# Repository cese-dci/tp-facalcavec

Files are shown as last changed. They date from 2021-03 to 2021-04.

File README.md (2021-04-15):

# Cargador modular de baterías industriales con acceso remoto

Repositorio perteneciente a la materia Diseño de circuitos impresos del CESE - 2021.

En el se encontrará el diseño del esquemático y PCB del TP final de la carrera.

&nbsp;

## Consideraciones de diseño del PCB

Se detallan a continuación los considerandos a tener en cuenta en el diseño y construcción del circuito impreso del cargador modular de baterías industriales.

### Dimensiones y ubicación
La placa debe adaptarse a un gabinete ya existente, por lo tanto sus medidas no deben superar los siguientes límites

Largo máximo      : 200 mm  
Ancho máximo      : 100 mm  

### Coordenadas de los agujero de montaje ( vista la placa de frente )

Agujero inferior izquierdo  : ( 0 mm, 0 mm )  
Agujero inferior derecho    : ( 184 mm, 0 mm )  
Agujero superior izquierdo  : ( 0 mm, -86 mm )  
Agujero superior derecho    : ( 184 mm, -86 mm )  

### Coordenadas del Display gráfico respecto del agujero inferior izquierdo

Ángulo inferior izquierdo   : ( 16 mm, -18.5 mm )  
Ángulo inferior derecho     : ( 102.5 mm, -18.5 mm )  
Ángulo superior izquierdo   : ( 16 mm, -72 mm )  
Ángulo superior derecho     : ( 102.5 mm, -72 mm )  

### Coordenadas del teclado respecto del agujero inferior izquierdo  
Centro botón 1    : ( 21 mm, -2 mm )  
Centro botón 2    : ( 46.7 mm, -2 mm )  
Centro botón 3    : ( 72 mm, -2 mm )  
Centro botón 4    : ( 997.5 mm, -2 mm )  

### Estándares de fabricación
Debido a la poca densidad de conexiones entre componentes el diseño se realizará en doble faz ( dos capas ).
&nbsp;
De acuerdo a la documentación aportada por el fabricantede PCB Mayer se implementará la tecnología “8MILS” donde  
&nbsp;
Diámetro de agujero: 16 mils / 0.40 mm  
Diámetro de pad o vía: 32 mils / 0.8 mm  
Ancho de traza: 8 mils / 0.20 mm  
Separación entre trazas: 7 mils / 0.18 mm  
Separación entre traza y pad: 6 mils / 0.15 mm  
Distancia de cobre a borde: 12 mils / 0.30 mm  
Altura - trazo de letras: 30 - 5  

### Componentes a utilizar  
Para el diseño de la placa se utilizarán componentes SMD para las resistencias, capacitores cerámicos y algunos circuitos integrados, mientras que el resto serán del tipo insertados (THT).  
Este criterio se debe a que la mayoría de los componentes que integran la placa se quieren adquirir en el mercado local.  
Para aprovechar el espacio disponible se colocaran componentes SMD en las dos caras del PCB.

### Método de armado
El tipo de armado y soldado de la placa se pretende hacer de forma manual

------------------------------------------------------------------------

&nbsp;

&nbsp;

<br />This work is licensed under a <a rel="license" href="http://creativecommons.org/licenses/by-nc-sa/4.0/">Creative Commons Attribution-NonCommercial-ShareAlike 4.0 International License</a>.

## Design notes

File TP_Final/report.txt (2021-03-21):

Info: Processing component "R106:/60563FFB:Resistor_THT:R_Axial_DIN0207_L6.3mm_D2.5mm_P7.62mm_Horizontal".
Info: Processing component "Q102:/6055EE01:Package_TO_SOT_THT:TO-92_HandSolder".
Info: Processing component "Q103:/60564001:Package_TO_SOT_THT:TO-92_HandSolder".
Info: Processing component "Q104:/605C896F:Package_TO_SOT_THT:TO-92_HandSolder".
Info: Processing component "Q106:/6064B820/606C59D1:Package_TO_SOT_THT:TO-92_HandSolder".
Info: Processing component "Q107:/6064B820/6066CC15:Package_TO_SOT_THT:TO-92_HandSolder".
Info: Processing component "Q108:/6064B820/6066A113:Package_TO_SOT_SMD:SOT-23".
Info: Processing component "R101:/6052A3FF:Resistor_THT:R_Axial_DIN0207_L6.3mm_D2.5mm_P7.62mm_Horizontal".
Info: Processing component "R102:/60530C1E:Resistor_THT:R_Axial_DIN0207_L6.3mm_D2.5mm_P7.62mm_Horizontal".
Info: Processing component "R103:/6055EDFB:Resistor_THT:R_Axial_DIN0207_L6.3mm_D2.5mm_P7.62mm_Horizontal".
Info: Processing component "R104:/6051AABC:Resistor_THT:R_Axial_DIN0207_L6.3mm_D2.5mm_P7.62mm_Horizontal".
Info: Processing component "R105:/6051B3A0:".
Info: Processing component "U103:/60512CA9:".
Info: Processing component "Q101:/60531C27:Package_TO_SOT_THT:TO-92_HandSolder".
Info: Processing component "R107:/605C8969:Resistor_THT:R_Axial_DIN0207_L6.3mm_D2.5mm_P7.62mm_Horizontal".
Info: Processing component "R109:/6064B820/606C59CB:Resistor_THT:R_Axial_DIN0207_L6.3mm_D2.5mm_P7.62mm_Horizontal".
Info: Processing component "R110:/6064B820/6066CC0F:Resistor_THT:R_Axial_DIN0207_L6.3mm_D2.5mm_P7.62mm_Horizontal".
Info: Processing component "R111:/6064B820/6066CC1B:Resistor_THT:R_Axial_DIN0207_L6.3mm_D2.5mm_P7.62mm_Horizontal".
Info: Processing component "R112:/6064B820/6066A5DE:Resistor_THT:R_Axial_DIN0207_L6.3mm_D2.5mm_P7.62mm_Horizontal".
Info: Processing component "R113:/6064B820/60669A26:Resistor_THT:R_Axial_DIN0207_L6.3mm_D2.5mm_P7.62mm_Horizontal".
Info: Processing component "SW101:/6064B820/606656EA:Button_Switch_THT:Push_E-Switch_KS01Q01".
Info: Processing component "SW102:/6064B820/60666642:Button_Switch_THT:Push_E-Switch_KS01Q01".
Info: Processing component "SW103:/6064B820/60666AB1:Button_Switch_THT:Push_E-Switch_KS01Q01".
Info: Processing component "SW104:/6064B820/60666FE4:Button_Switch_THT:Push_E-Switch_KS01Q01".
Info: Processing component "U101:/60526B5F:".
Info: Processing component "U102:/6050F213:Package_QFP:LQFP-64_10x10mm_P0.5mm".
Info: Processing component "J101:/60547902:".
Info: Processing component "BZ102:/6064B820/606C59D7:".
Info: Processing component "C101:/6052AAFE:Capacitor_THT:C_Disc_D5.0mm_W2.5mm_P5.00mm".
Info: Processing component "C102:/60522B51:Capacitor_THT:C_Disc_D5.0mm_W2.5mm_P5.00mm".
Info: Processing component "C103:/605236AF:Capacitor_THT:C_Disc_D5.0mm_W2.5mm_P5.00mm".
Info: Processing component "C104:/60523EB6:Capacitor_THT:C_Disc_D5.0mm_W2.5mm_P5.00mm".
Info: Processing component "C105:/60524DA4:Capacitor_THT:C_Disc_D5.0mm_W2.5mm_P5.00mm".
Info: Processing component "D101:/60534B59:Diode_THT:D_DO-41_SOD81_P7.62mm_Horizontal".
Info: Processing component "D102:/6055EE0D:Diode_THT:D_DO-41_SOD81_P7.62mm_Horizontal".
Info: Processing component "D103:/6056400D:Diode_THT:D_DO-41_SOD81_P7.62mm_Horizontal".
Info: Processing component "D104:/605C897B:Diode_THT:D_DO-41_SOD81_P7.62mm_Horizontal".
Info: Processing component "D105:/6064B820/60670CAA:LED_THT:LED_D5.0mm-3".
Info: Processing component "DS?101:/6064B820/60662467:Cargador_Modular:3.5_TFT_DISPLAY".
Info: Processing component "Y102:/6051FEB7:".
Info: Processing component "J102:/6055EE23:".
Info: Processing component "J103:/60564023:".
Info: Processing component "Y101:/60521572:".
Info: Processing component "J104:/605E35C6:".
Info: Processing component "K101:/6068FE4F:Relay_THT:Relay_DPDT_Kemet_EC2".
Info: Processing component "K102:/606A5B03:Relay_THT:Relay_DPDT_Kemet_EC2".
Info: Processing component "K103:/606A82C3:Relay_THT:Relay_DPDT_Kemet_EC2".
Info: Processing component "K104:/606A9DDE:Relay_THT:Relay_DPDT_Kemet_EC2".
Error: Cannot add Y102 (no footprint assigned).
Error: Cannot add Y101 (no footprint assigned).
Error: Cannot add U103 (no footprint assigned).
Error: Cannot add U101 (no footprint assigned).
Error: Cannot add R105 (no footprint assigned).
Error: Cannot add J104 (no footprint assigned).
Error: Cannot add J103 (no footprint assigned).
Error: Cannot add J102 (no footprint assigned).
Error: Cannot add J101 (no footprint assigned).
Error: Cannot add BZ102 (no footprint assigned).

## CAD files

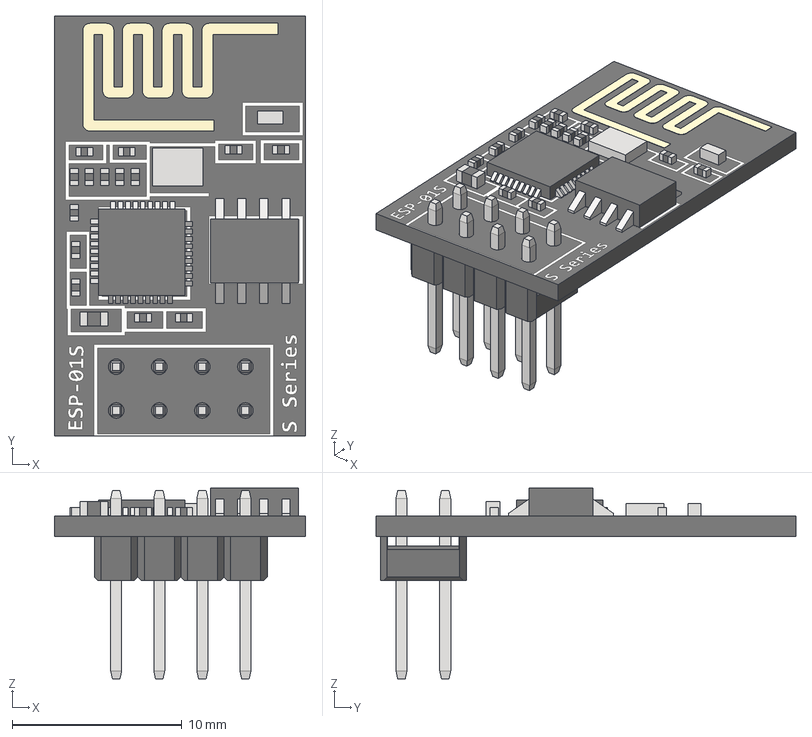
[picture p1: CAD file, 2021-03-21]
TP_Final/New3D/ESP-01S (ESP8266) Board Module.step
14.8 x 24.8 x 11.2 mm
PCB
Antenna
SerialFlashMem
ESP8266EX
Male Pin Header 2x4
SmalComponent x 14
LargeComponent
LED
Crystal

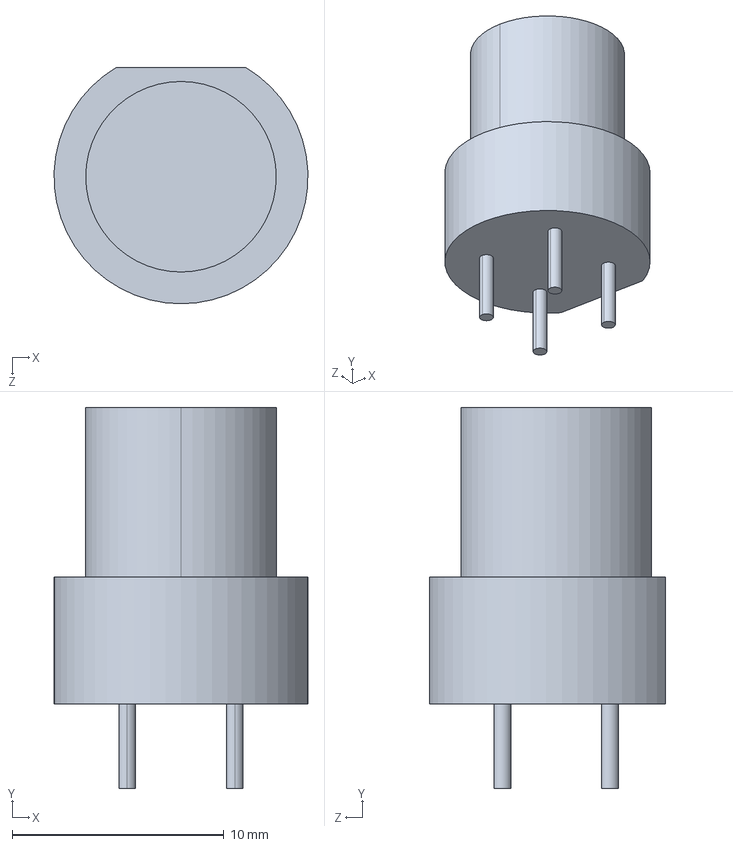
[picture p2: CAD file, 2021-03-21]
TP_Final/New3D/Push_E-Switch_KS01Q01.STEP
12.0 x 18.0 x 11.2 mm

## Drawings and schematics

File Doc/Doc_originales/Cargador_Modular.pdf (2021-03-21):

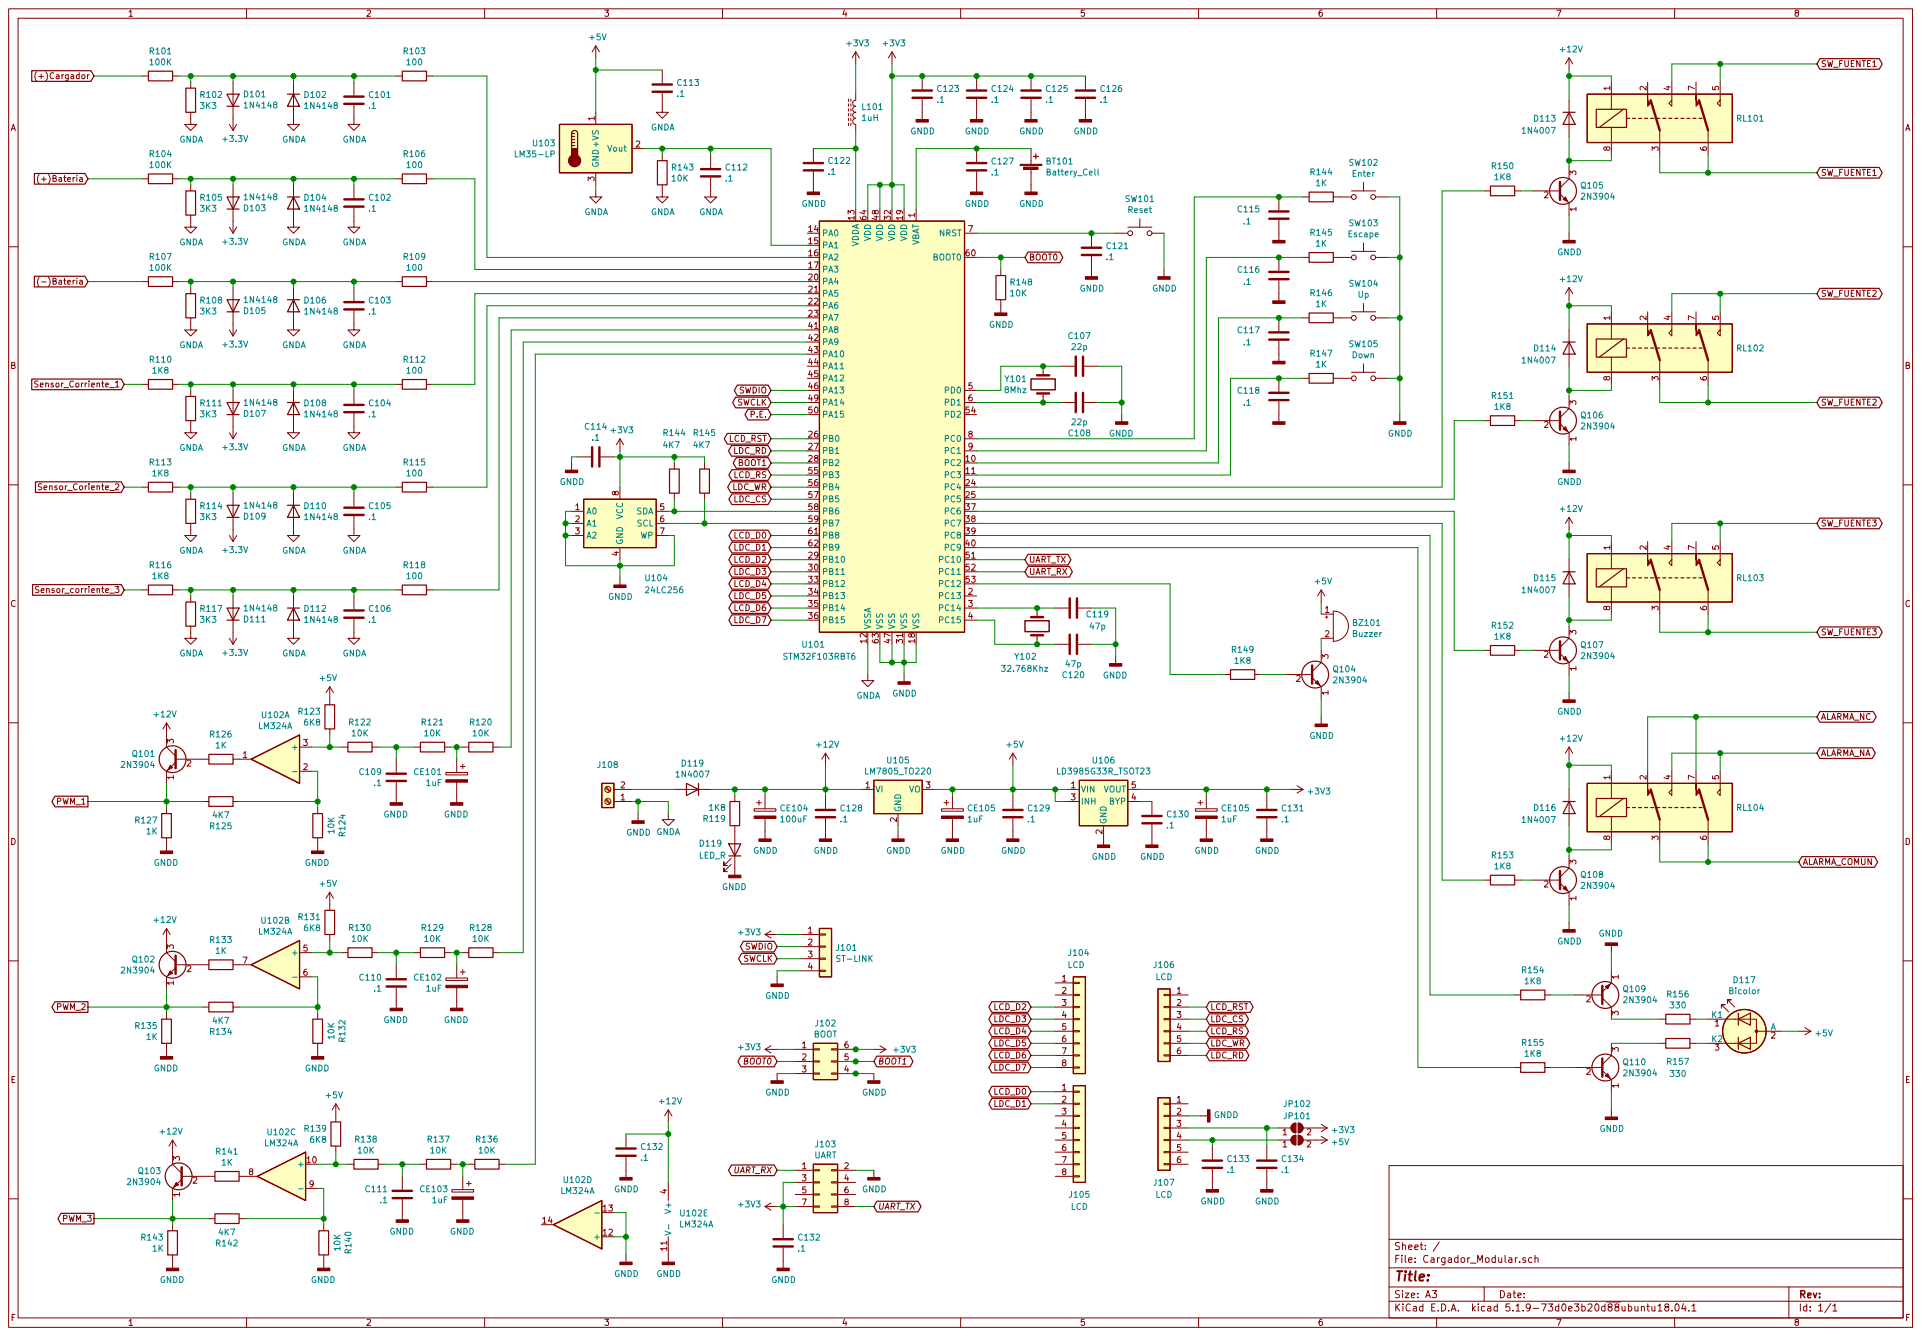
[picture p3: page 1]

1 VDD 19 VDD 32 VDD 48 VDD 64 VDDA 13 VSS 18 VSS 31 VSS 47 VSS 63 VSSA 12 U101 STM32F103RBT6 GNDD

4 SDA 5 SCL 6 WP 7 VCC

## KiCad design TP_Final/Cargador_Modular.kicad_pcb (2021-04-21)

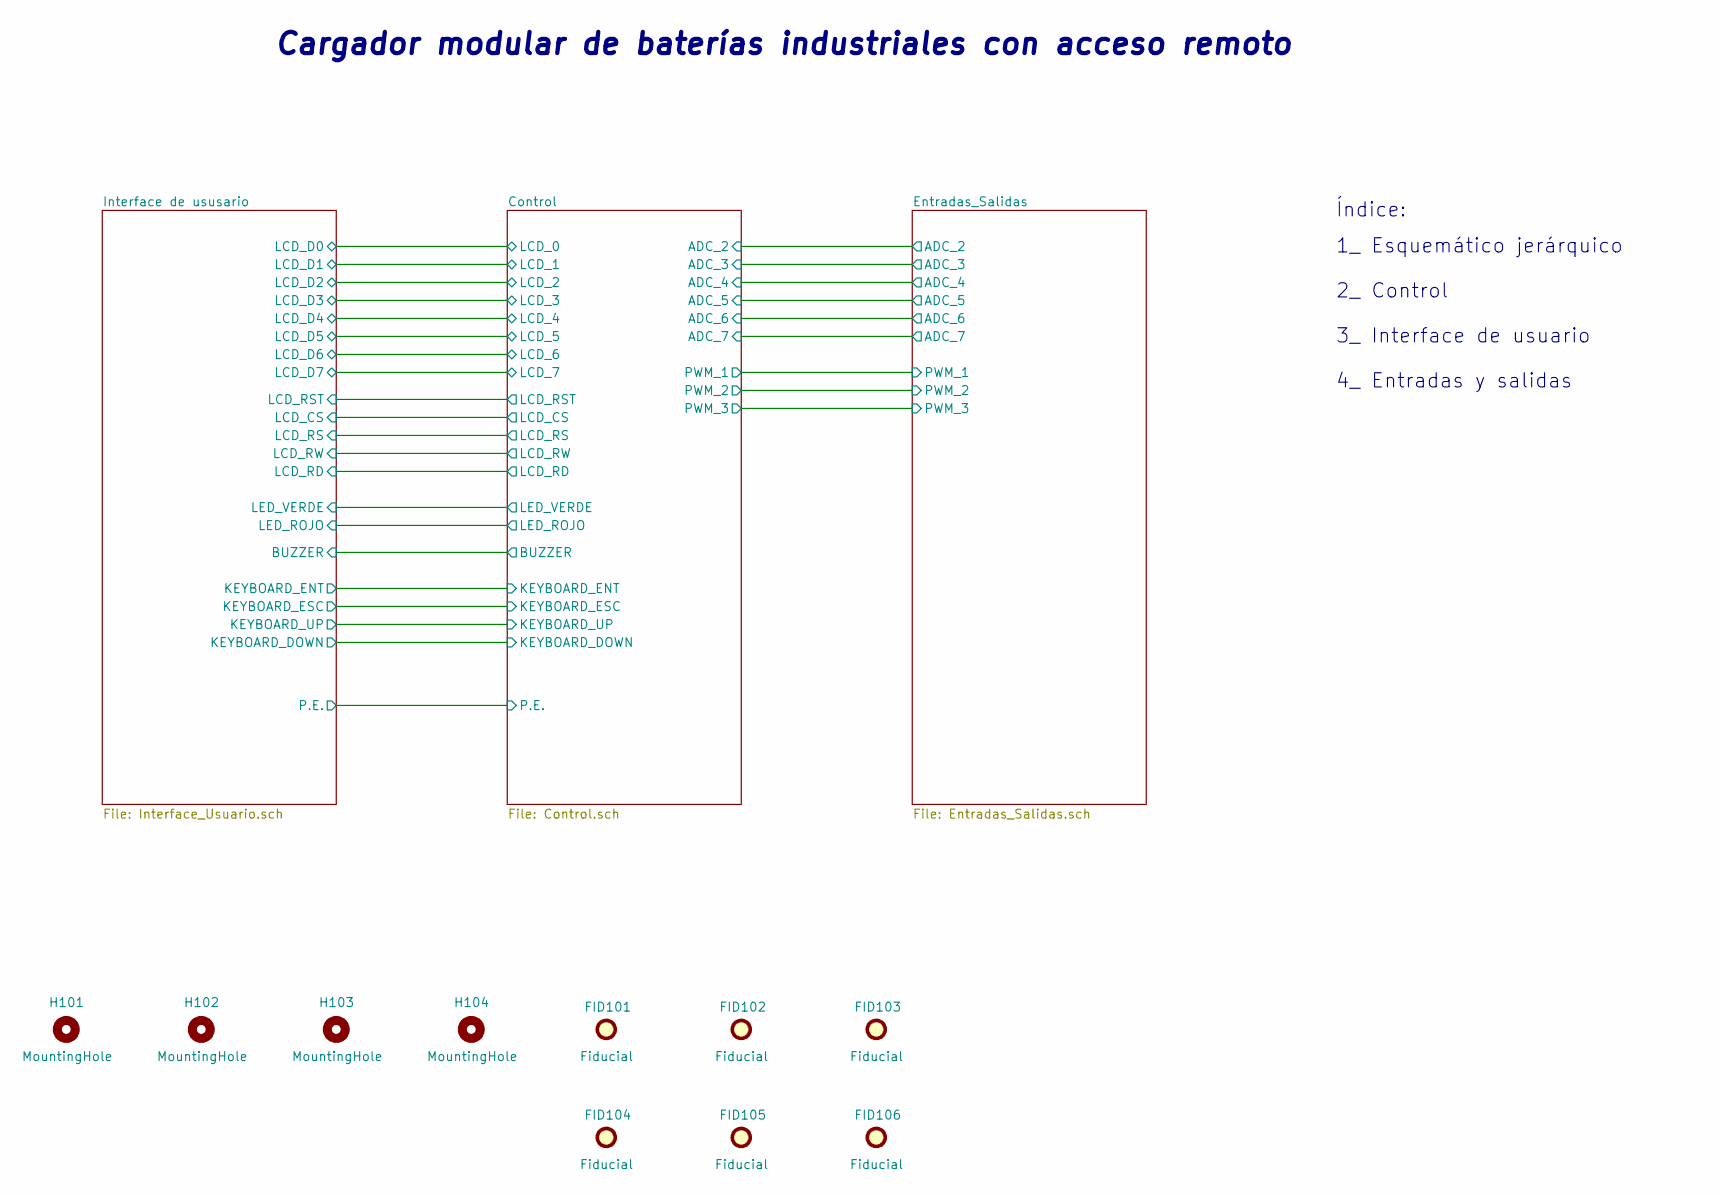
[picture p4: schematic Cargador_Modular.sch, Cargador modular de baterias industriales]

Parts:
FID101, FID102, FID103, FID104, FID105, FID106: Fiducial; Fiducial_0.75mm_Mask1.5mm
H101, H102, H103, H104: MountingHole; MountingHole_4.5mm_Pad

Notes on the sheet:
Cargador modular de baterías industriales con acceso remoto
4_ Entradas y salidas
3_ Interface de usuario
2_ Control
1_ Esquemático jerárquico
Índice:

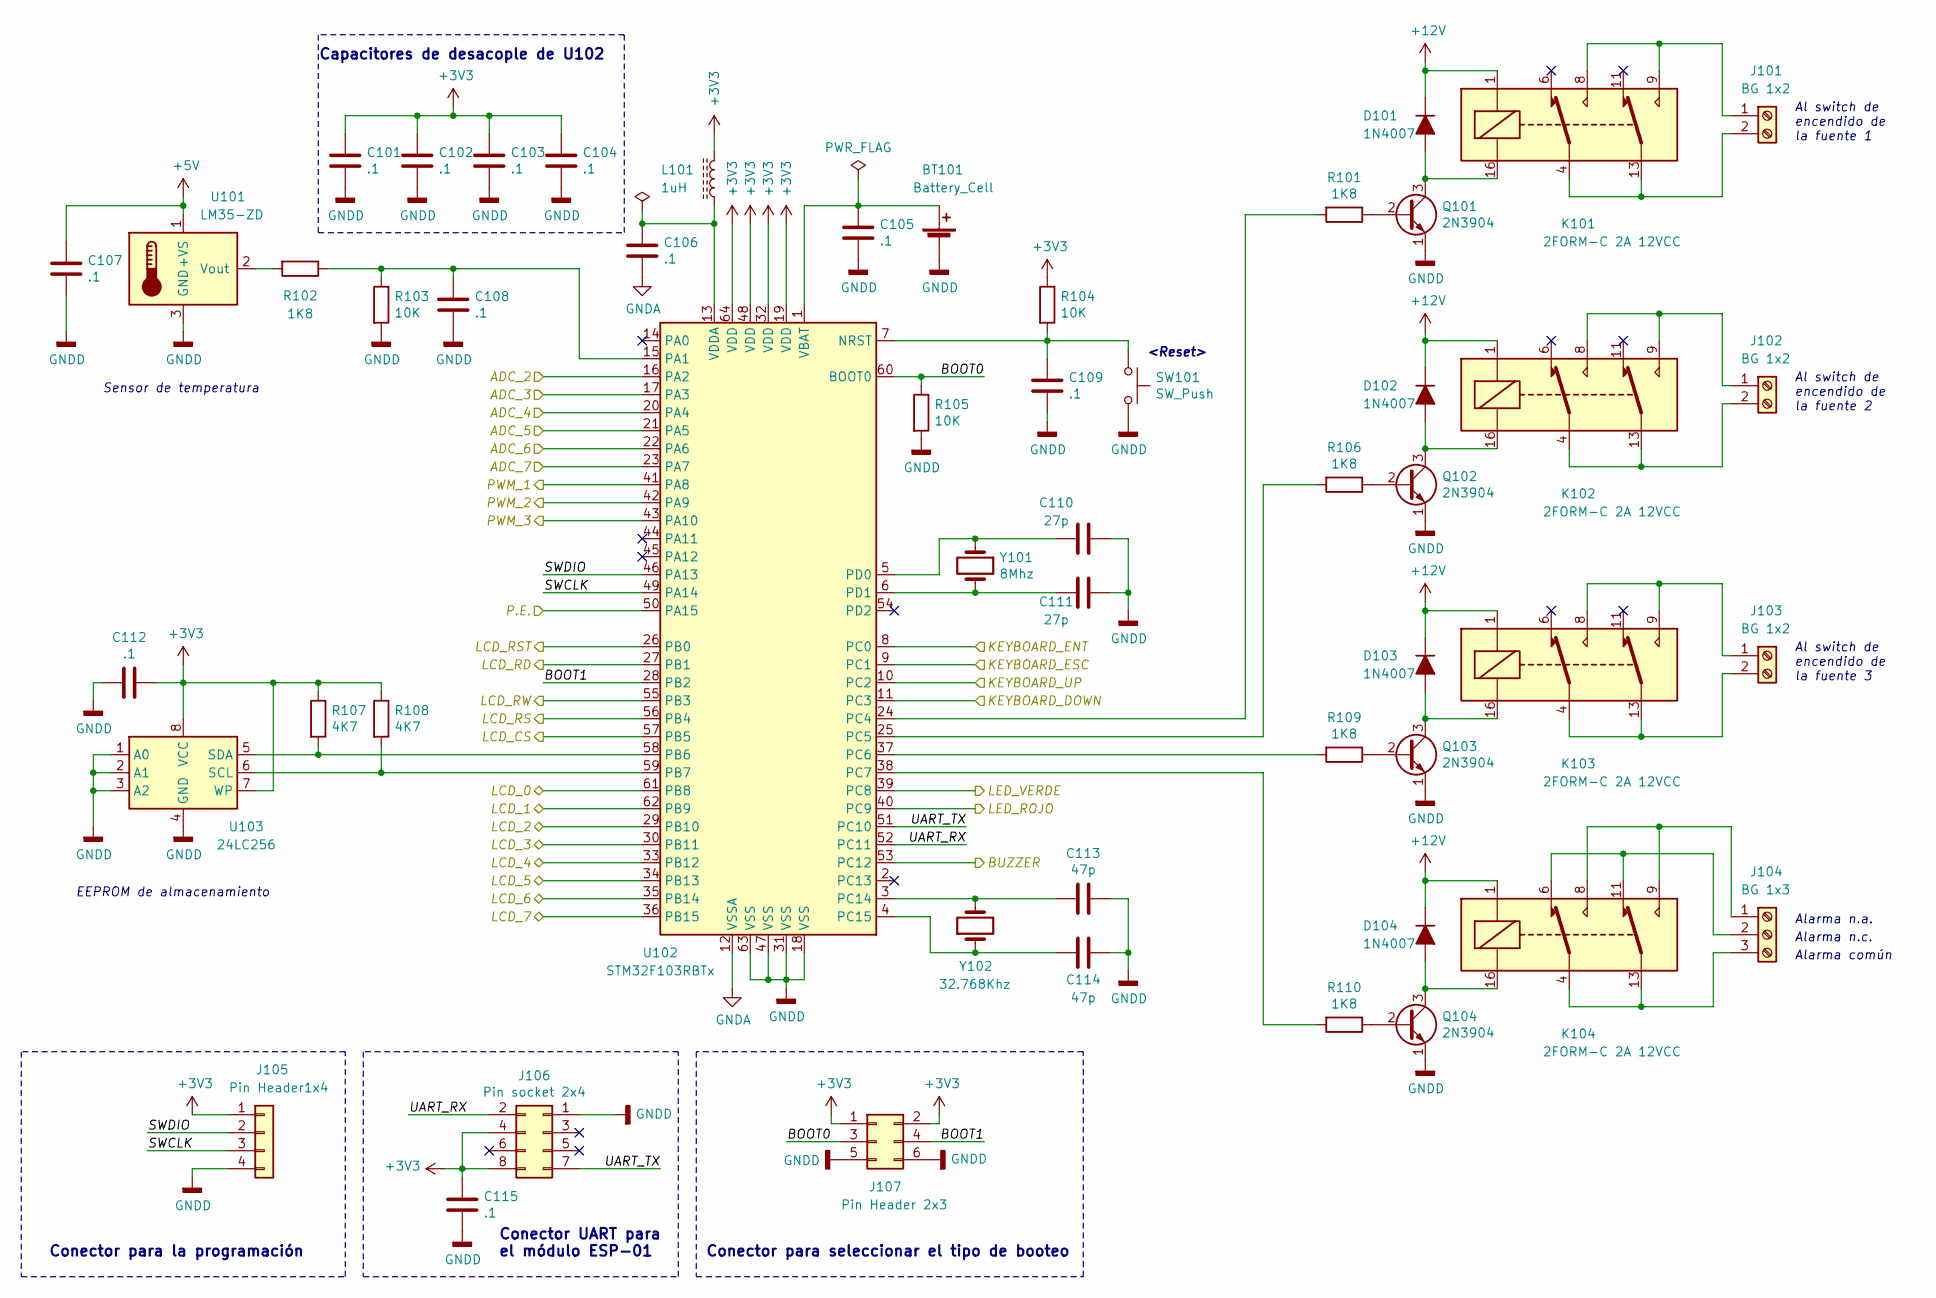
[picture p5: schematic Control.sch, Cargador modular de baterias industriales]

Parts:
BT101: Battery_Cell; BatteryHolder_Keystone_3034_1x20mm; Digikey part 36-2997-ND
C101, C102, C103, C104, C105, C106, C107, C108, C109, C112, C115: .1; C_0805_2012Metric
C110, C111: 27p; C_0805_2012Metric
C113, C114: 47p; C_0805_2012Metric
D101, D102, D103, D104: 1N4007; D_DO-41_SOD81_P10.16mm_Horizontal
J101, J102, J103: BG 1x2; TerminalBlock_Phoenix_PT-1,5-2-5.0-H_1x02_P5.00mm_Horizontal
J104: BG 1x3; TerminalBlock_Phoenix_PT-1,5-3-5.0-H_1x03_P5.00mm_Horizontal
J105: Pin Header1x4; PinHeader_1x04_P2.54mm_Vertical
J106: Pin socket 2x4; PinSocket_2x04_P2.54mm_Vertical
J107: Pin Header 2x3; PinHeader_2x03_P2.54mm_Vertical
K101, K102, K103, K104: 2FORM-C 2A 12VCC; Relay_DPDT_Omron_G5V-2
L101: 1uH; L_Axial_L5.3mm_D2.2mm_P7.62mm_Horizontal_Vishay_IM-1
Q101, Q102, Q103, Q104: 2N3904; TO-92_HandSolder
R101, R102, R106, R109, R110: 1K8; R_1206_3216Metric
R103, R104, R105: 10K; R_1206_3216Metric
R107, R108: 4K7; R_1206_3216Metric
SW101: SW_Push; SW_PUSH_6mm_H4.3mm
U101: LM35-ZD; TO-92_HandSolder; Digikey part 296-35151-1-ND
U102: STM32F103RBTx; LQFP-64_10x10mm_P0.5mm; Digikey part 497-6066-ND
U103: 24LC256; SOIC-8_3.9x4.9mm_P1.27mm; Digikey part 24LC256T-I/SNDKR-ND
Y101: 8Mhz; Crystal_HC49-4H_Vertical
Y102: 32.768Khz; Crystal_C26-LF_D2.1mm_L6.5mm_Horizontal_1EP_style2

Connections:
+3V3: C101.1, C102.1, C103.1, C104.1, C112.1, C115.1, J105.1, J106.4, J106.8, J107.1, J107.2, L101.2, R104.1, R107.1, R108.1, U102.19 (VDD), U102.32 (VDD), U102.48 (VDD), U102.64 (VDD), U103.7 (WP), U103.8 (VCC); also elsewhere on the board
+5V: C107.1, U101.1 (+VS); also elsewhere on the board
+12V: D101.1 (K), D102.1 (K), D103.1 (K), D104.1 (K), K101.1, K102.1, K103.1, K104.1; also elsewhere on the board
/Control/ADC_2: U102.16 (PA2); also elsewhere on the board
/Control/ADC_3: U102.17 (PA3); also elsewhere on the board
/Control/ADC_4: U102.20 (PA4); also elsewhere on the board
/Control/ADC_5: U102.21 (PA5); also elsewhere on the board
/Control/ADC_6: U102.22 (PA6); also elsewhere on the board
/Control/ADC_7: U102.23 (PA7); also elsewhere on the board
/Control/BOOT0: J107.3, R105.1, U102.60 (BOOT0)
/Control/BOOT1: J107.4, U102.28 (PB2)
/Control/BUZZER: U102.53 (PC12); also elsewhere on the board
/Control/KEYBOARD_DOWN: U102.11 (PC3); also elsewhere on the board
/Control/KEYBOARD_ENT: U102.8 (PC0); also elsewhere on the board
/Control/KEYBOARD_ESC: U102.9 (PC1); also elsewhere on the board
/Control/KEYBOARD_UP: U102.10 (PC2); also elsewhere on the board
/Control/LCD_0: U102.61 (PB8); also elsewhere on the board
/Control/LCD_1: U102.62 (PB9); also elsewhere on the board
/Control/LCD_2: U102.29 (PB10); also elsewhere on the board
/Control/LCD_3: U102.30 (PB11); also elsewhere on the board
/Control/LCD_4: U102.33 (PB12); also elsewhere on the board
/Control/LCD_5: U102.34 (PB13); also elsewhere on the board
/Control/LCD_6: U102.35 (PB14); also elsewhere on the board
/Control/LCD_7: U102.36 (PB15); also elsewhere on the board
/Control/LCD_CS: U102.57 (PB5); also elsewhere on the board
/Control/LCD_RD: U102.27 (PB1); also elsewhere on the board
/Control/LCD_RS: U102.56 (PB4); also elsewhere on the board
/Control/LCD_RST: U102.26 (PB0); also elsewhere on the board
/Control/LCD_RW: U102.55 (PB3); also elsewhere on the board
/Control/LED_ROJO: U102.40 (PC9); also elsewhere on the board
/Control/LED_VERDE: U102.39 (PC8); also elsewhere on the board
/Control/P.E.: U102.50 (PA15); also elsewhere on the board
/Control/PWM_1: U102.41 (PA8); also elsewhere on the board
/Control/PWM_2: U102.42 (PA9); also elsewhere on the board
/Control/PWM_3: U102.43 (PA10); also elsewhere on the board
/Control/SWCLK: J105.3, U102.49 (PA14)
/Control/SWDIO: J105.2, U102.46 (PA13)
/Control/UART_RX: J106.2, U102.52 (PC11)
/Control/UART_TX: J106.7, U102.51 (PC10)
GNDA: BT101.2 (-), C101.2, C102.2, C103.2, C104.2, C105.2, C106.2, C107.2, C108.2, C109.2, C110.1, C111.1, C112.2, C113.1, C114.1, C115.2, J105.4, J106.1, J107.5, J107.6, Q101.1 (E), Q102.1 (E), Q103.1 (E), Q104.1 (E), R103.2, R105.2, SW101.2, U101.3 (GND), U102.12 (VSSA), U102.18 (VSS), U102.31 (VSS), U102.47 (VSS), U102.63 (VSS), U103.1 (A0), U103.2 (A1), U103.3 (A2), U103.4 (GND); also elsewhere on the board
unnamed: BT101.1 (+), C105.1, U102.1 (VBAT)
unnamed: C106.1, L101.1, U102.13 (VDDA)
unnamed: C108.1, R102.1, R103.1, U102.15 (PA1)
unnamed: C109.1, R104.2, SW101.1, U102.7 (NRST)
unnamed: C110.2, U102.5 (PD0), Y101.1
unnamed: C111.2, U102.6 (PD1), Y101.2
unnamed: C113.2, U102.3 (PC14), Y102.2
unnamed: C114.2, U102.4 (PC15), Y102.1
unnamed: D101.2 (A), K101.16, Q101.3 (C)
unnamed: D102.2 (A), K102.16, Q102.3 (C)
unnamed: D103.2 (A), K103.16, Q103.3 (C)
unnamed: D104.2 (A), K104.16, Q104.3 (C)
unnamed: J101.1, K101.8, K101.9
unnamed: J101.2, K101.4, K101.13
unnamed: J102.1, K102.8, K102.9
unnamed: J102.2, K102.4, K102.13
unnamed: J103.1, K103.8, K103.9
unnamed: J103.2, K103.4, K103.13
unnamed: J104.1, K104.8, K104.9
unnamed: J104.2, K104.6, K104.11
unnamed: J104.3, K104.4, K104.13
unnamed: Q101.2 (B), R101.1
unnamed: Q102.2 (B), R106.1
unnamed: Q103.2 (B), R109.1
unnamed: Q104.2 (B), R110.1
unnamed: R101.2, U102.24 (PC4)
unnamed: R102.2, U101.2 (Vout)
unnamed: R106.2, U102.25 (PC5)
unnamed: R107.2, U102.58 (PB6), U103.5 (SDA)
unnamed: R108.2, U102.59 (PB7), U103.6 (SCL)
unnamed: R109.2, U102.37 (PC6)
unnamed: R110.2, U102.38 (PC7)

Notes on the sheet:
Conector para la programación
Conector UART para el módulo ESP-01
Conector para seleccionar el tipo de booteo
Al switch de encendido de la fuente 1
Al switch de encendido de la fuente 2
Al switch de encendido de la fuente 3
Alarma común
Alarma n.a.
Alarma n.c.
Sensor de temperatura
EEPROM de almacenamiento
<Reset>
Capacitores de desacople de U102

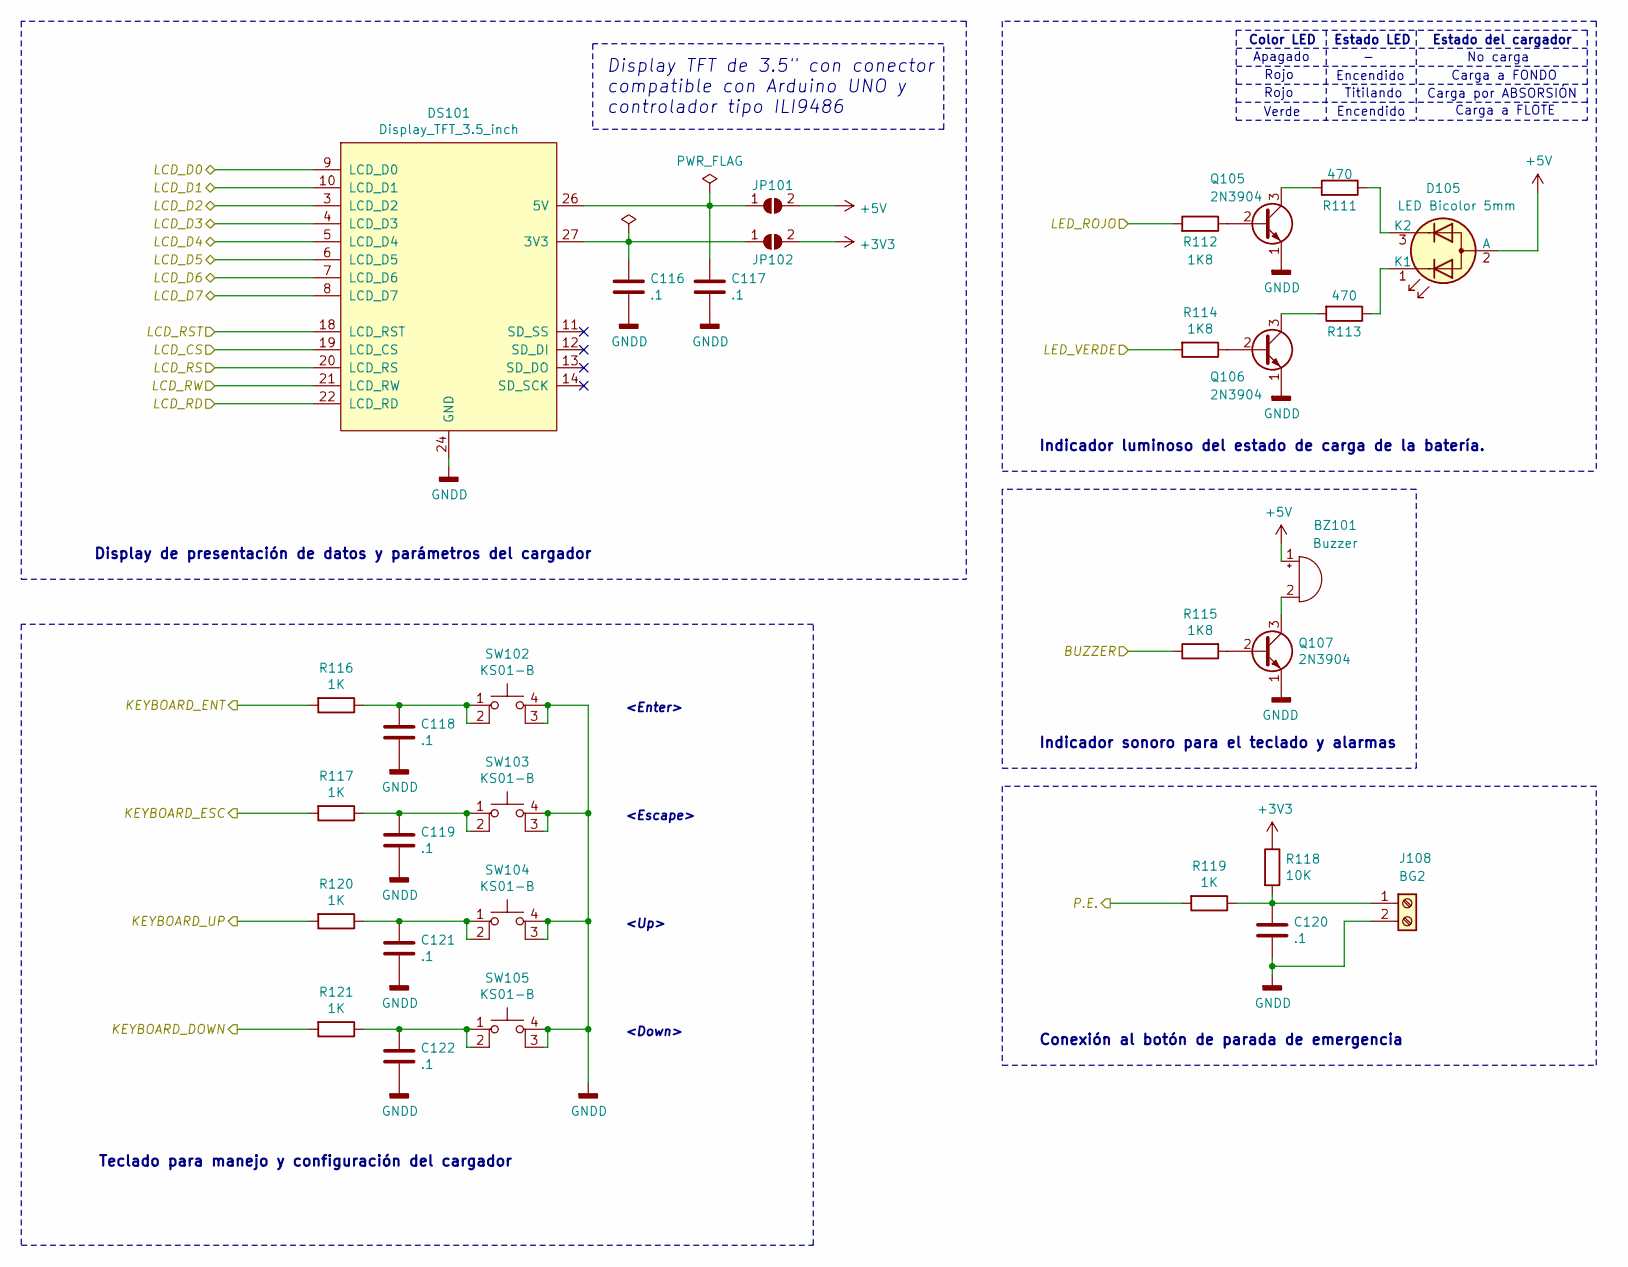
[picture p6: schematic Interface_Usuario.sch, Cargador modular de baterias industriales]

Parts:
BZ101: Buzzer; Buzzer_12x9.5RM7.6
C116, C117, C118, C119, C120, C121, C122: .1; C_0805_2012Metric
D105: LED Bicolor 5mm; LED_D5.0mm-3; Digikey part 1080-1110-ND
DS101: Display_TFT_3.5_inch; Part # N/A
J108: BG2; TerminalBlock_Phoenix_PT-1,5-2-5.0-H_1x02_P5.00mm_Horizontal
JP101, JP102: SolderJumper_2_Open; SolderJumper-2_P1.3mm_Open_RoundedPad1.0x1.5mm
Q105, Q106, Q107: 2N3904; TO-92_HandSolder
R111, R113: 470; R_1206_3216Metric
R112, R114, R115: 1K8; R_1206_3216Metric
R116, R117, R119, R120, R121: 1K; R_1206_3216Metric
R118: 10K; R_1206_3216Metric
SW102, SW103, SW104, SW105: KS01-B; Push_E-Switch_KS01Q01

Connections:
+3V3: JP102.2 (B), R118.1; also elsewhere on the board
+5V: BZ101.1 (-), D105.2 (A), JP101.2 (B); also elsewhere on the board
/Control/BUZZER: R115.1; also elsewhere on the board
/Control/KEYBOARD_DOWN: R121.2; also elsewhere on the board
/Control/KEYBOARD_ENT: R116.2; also elsewhere on the board
/Control/KEYBOARD_ESC: R117.2; also elsewhere on the board
/Control/KEYBOARD_UP: R120.2; also elsewhere on the board
/Control/LCD_0: DS101.9 (LCD_D0); also elsewhere on the board
/Control/LCD_1: DS101.10 (LCD_D1); also elsewhere on the board
/Control/LCD_2: DS101.3 (LCD_D2); also elsewhere on the board
/Control/LCD_3: DS101.4 (LCD_D3); also elsewhere on the board
/Control/LCD_4: DS101.5 (LCD_D4); also elsewhere on the board
/Control/LCD_5: DS101.6 (LCD_D5); also elsewhere on the board
/Control/LCD_6: DS101.7 (LCD_D6); also elsewhere on the board
/Control/LCD_7: DS101.8 (LCD_D7); also elsewhere on the board
/Control/LCD_CS: DS101.19 (LCD_CS); also elsewhere on the board
/Control/LCD_RD: DS101.22 (LCD_RD); also elsewhere on the board
/Control/LCD_RS: DS101.20 (LCD_RS); also elsewhere on the board
/Control/LCD_RST: DS101.18 (LCD_RST); also elsewhere on the board
/Control/LCD_RW: DS101.21 (LCD_RW); also elsewhere on the board
/Control/LED_ROJO: R112.2; also elsewhere on the board
/Control/LED_VERDE: R114.2; also elsewhere on the board
/Control/P.E.: R119.2; also elsewhere on the board
GNDA: C116.2, C117.2, C118.2, C119.2, C120.2, C121.2, C122.2, DS101.24 (GND), J108.2, Q105.1 (E), Q106.1 (E), Q107.1 (E), SW102.3 (K), SW102.4 (A), SW103.3 (K), SW103.4 (A), SW104.3 (K), SW104.4 (A), SW105.3 (K), SW105.4 (A); also elsewhere on the board
unnamed: BZ101.2 (+), Q107.3 (C)
unnamed: C116.1, DS101.27 (3V3), JP102.1 (A)
unnamed: C117.1, DS101.26 (5V), JP101.1 (A)
unnamed: C118.1, R116.1, SW102.1, SW102.2
unnamed: C119.1, R117.1, SW103.1, SW103.2
unnamed: C120.1, J108.1, R118.2, R119.1
unnamed: C121.1, R120.1, SW104.1, SW104.2
unnamed: C122.1, R121.1, SW105.1, SW105.2
unnamed: D105.1 (K1), R113.1
unnamed: D105.3 (K2), R111.1
unnamed: Q105.2 (B), R112.1
unnamed: Q105.3 (C), R111.2
unnamed: Q106.2 (B), R114.1
unnamed: Q106.3 (C), R113.2
unnamed: Q107.2 (B), R115.2

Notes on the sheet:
Indicador luminoso del estado de carga de la batería.
Indicador sonoro para el teclado y alarmas
Conexión al botón de parada de emergencia
Color LED
Estado LED
Estado del cargador
Rojo
Apagado
No carga
Encendido
Carga a FONDO
Titilando
Carga por ABSORSIÓN
Verde
Carga a FLOTE
<Down>
<Up>
<Escape>
<Enter>
Teclado para manejo y configuración del cargador
Display de presentación de datos y parámetros del cargador
Display TFT de 3.5" con conector compatible con Arduino UNO y controlador tipo ILI9486

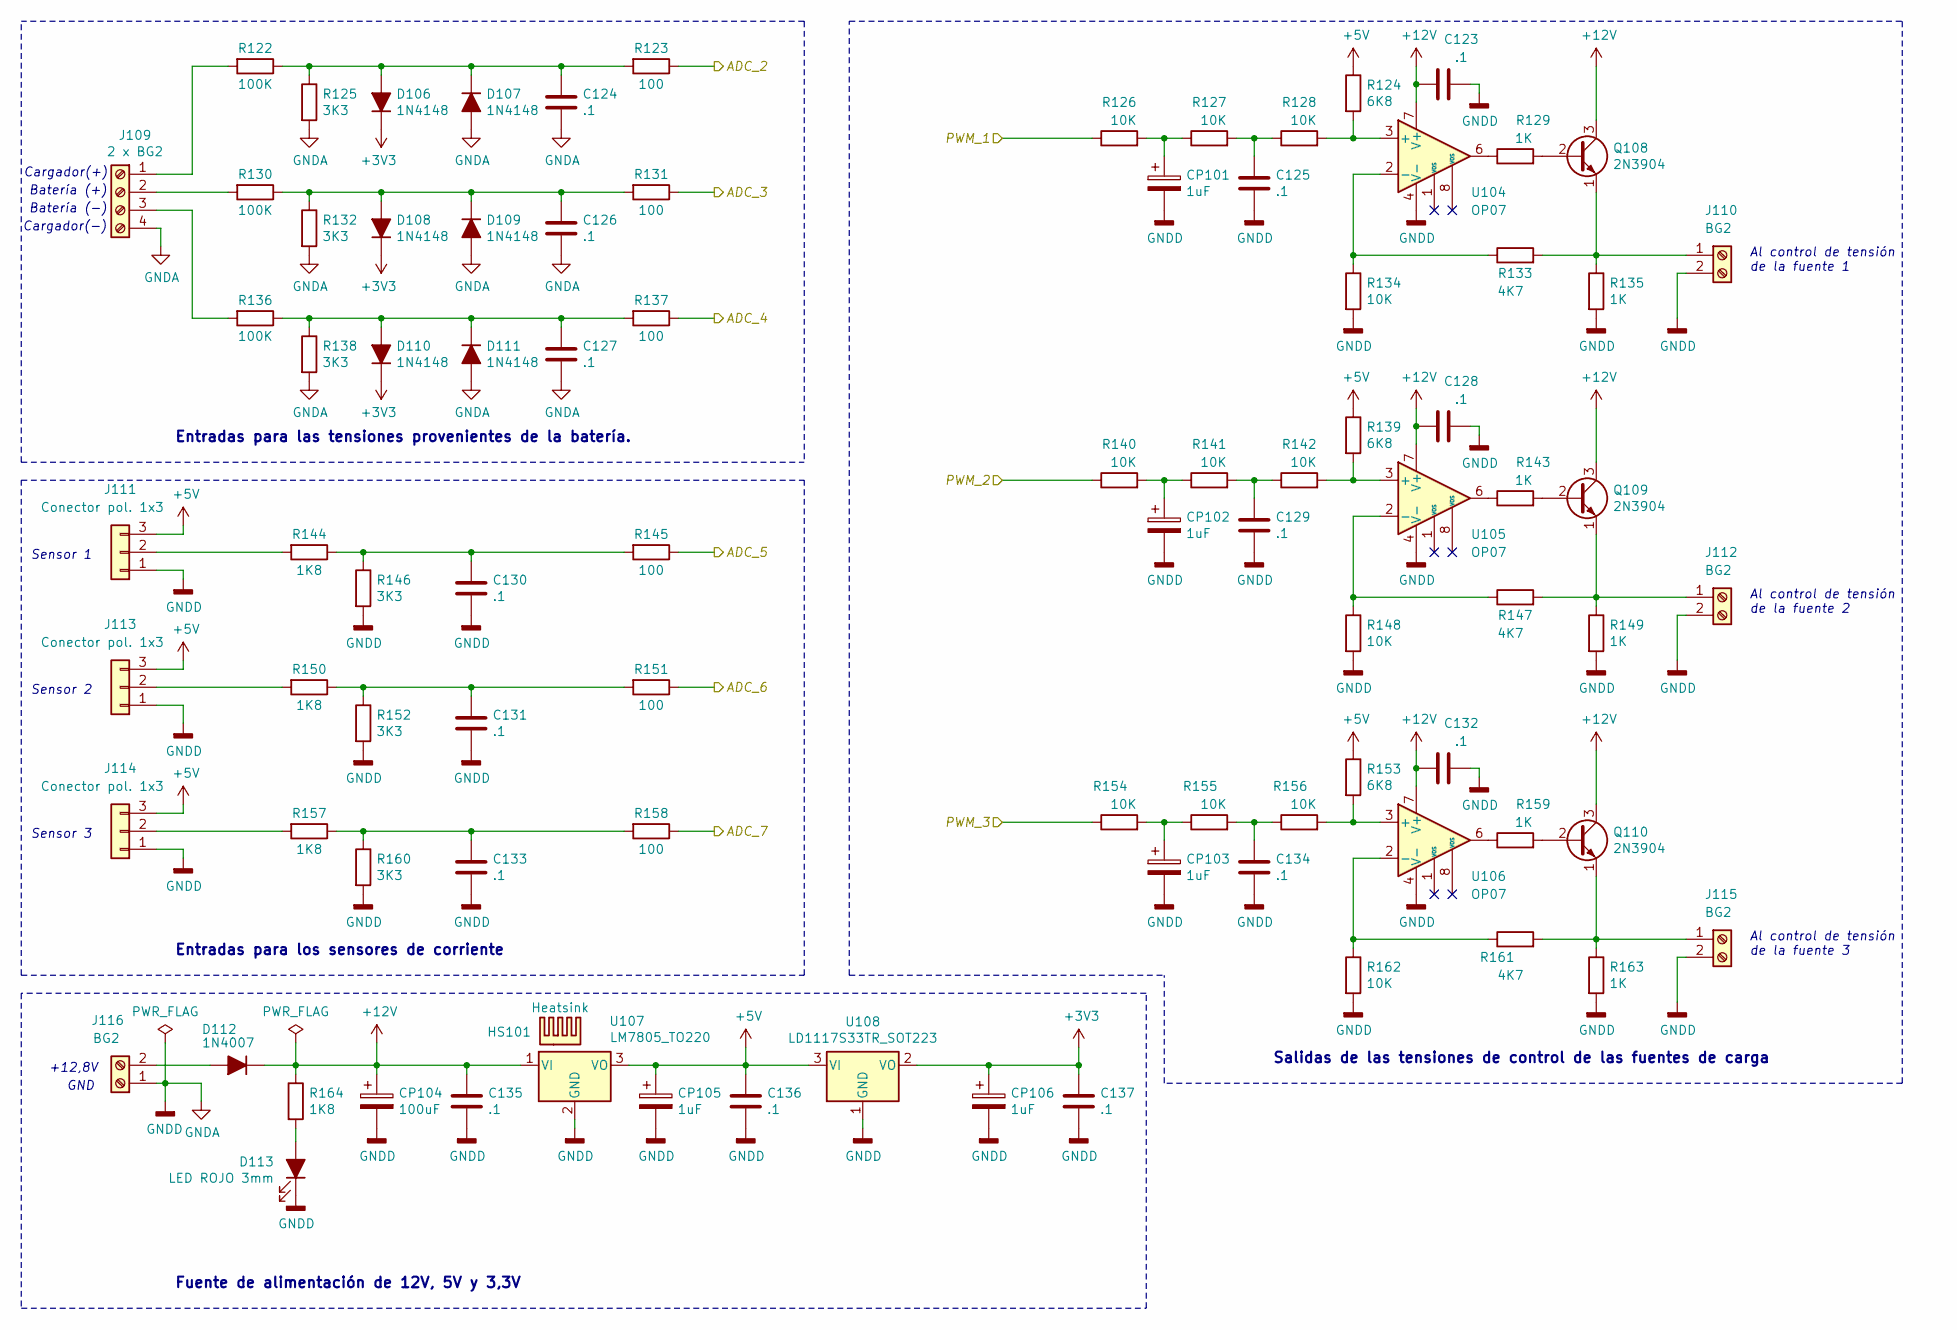
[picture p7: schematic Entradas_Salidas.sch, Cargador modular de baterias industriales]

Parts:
C123, C124, C125, C126, C127, C128, C129, C130, C131, C132, C133, C134, C135, C136, C137: .1; C_0805_2012Metric
CP101, CP102, CP103, CP105, CP106: 1uF; CP_Radial_D5.0mm_P2.50mm
CP104: 100uF; CP_Radial_D6.3mm_P2.50mm
D106, D107, D108, D109, D110, D111: 1N4148; D_A-405_P7.62mm_Horizontal
D112: 1N4007; D_DO-41_SOD81_P10.16mm_Horizontal
D113: LED ROJO 3mm; LED_D3.0mm
HS101: Heatsink; Heatsink_Aavid-TV5G_TO220_Horizontal
J109: 2 x BG2; TerminalBlock_Phoenix_PT-1,5-4-5.0-H_1x04_P5.00mm_Horizontal
J110, J112, J115, J116: BG2; TerminalBlock_Phoenix_PT-1,5-2-5.0-H_1x02_P5.00mm_Horizontal
J111, J113, J114: Conector pol. 1x3; JST_EH_B3B-EH-A_1x03_P2.50mm_Vertical
Q108, Q109, Q110: 2N3904; TO-92_HandSolder
R122, R130, R136: 100K; R_1206_3216Metric
R123, R131, R137, R145, R151, R158: 100; R_1206_3216Metric
R124, R139, R153: 6K8; R_1206_3216Metric
R125, R132, R138, R146, R152, R160: 3K3; R_1206_3216Metric
R126, R127, R128, R134, R140, R141, R142, R148, R154, R155, R156, R162: 10K; R_1206_3216Metric
R129, R135, R143, R149, R159, R163: 1K; R_1206_3216Metric
R133, R147, R161: 4K7; R_1206_3216Metric
R144, R150, R157, R164: 1K8; R_1206_3216Metric
U104, U105: OP07; DIP-8_W7.62mm_LongPads
U106: OP07; DIP-8_W7.62mm_LongPads; Digikey part OP07DNZ-ND
U107: LM7805_TO220; TO-220-3_Horizontal_TabDown; Digikey part MC7805ACTGOS-ND
U108: LD1117S33TR_SOT223; SOT-223-3_TabPin2; Digikey part 497-1242-1-ND

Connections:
+3V3: C137.1, CP106.1, D106.1 (K), D108.1 (K), D110.1 (K), U108.2 (VO); also elsewhere on the board
+5V: C136.1, CP105.1, J111.3, J113.3, J114.3, R124.1, R139.1, R153.1, U107.3 (VO), U108.3 (VI); also elsewhere on the board
+12V: C123.2, C128.2, C132.2, C135.1, CP104.1, D112.1 (K), Q108.3 (C), Q109.3 (C), Q110.3 (C), R164.1, U104.7 (V+), U105.7 (V+), U106.7 (V+), U107.1 (VI); also elsewhere on the board
/Control/ADC_2: R123.1; also elsewhere on the board
/Control/ADC_3: R131.1; also elsewhere on the board
/Control/ADC_4: R137.1; also elsewhere on the board
/Control/ADC_5: R145.1; also elsewhere on the board
/Control/ADC_6: R151.1; also elsewhere on the board
/Control/ADC_7: R158.1; also elsewhere on the board
/Control/PWM_1: R126.1; also elsewhere on the board
/Control/PWM_2: R140.1; also elsewhere on the board
/Control/PWM_3: R154.1; also elsewhere on the board
GNDA: C123.1, C124.2, C125.2, C126.2, C127.2, C128.1, C129.2, C130.2, C131.2, C132.1, C133.2, C134.2, C135.2, C136.2, C137.2, CP101.2, CP102.2, CP103.2, CP104.2, CP105.2, CP106.2, D107.2 (A), D109.2 (A), D111.2 (A), D113.1 (K), J109.4, J110.2, J111.1, J112.2, J113.1, J114.1, J115.2, J116.1, R125.2, R132.2, R134.2, R135.2, R138.2, R146.2, R148.2, R149.2, R152.2, R160.2, R162.2, R163.2, U104.4 (V-), U105.4 (V-), U106.4 (V-), U107.2 (GND), U108.1 (GND); also elsewhere on the board
unnamed: C124.1, D106.2 (A), D107.1 (K), R122.1, R123.2, R125.1
unnamed: C125.1, R127.2, R128.1
unnamed: C126.1, D108.2 (A), D109.1 (K), R130.1, R131.2, R132.1
unnamed: C127.1, D110.2 (A), D111.1 (K), R136.1, R137.2, R138.1
unnamed: C129.1, R141.2, R142.1
unnamed: C130.1, R144.1, R145.2, R146.1
unnamed: C131.1, R150.1, R151.2, R152.1
unnamed: C133.1, R157.1, R158.2, R160.1
unnamed: C134.1, R155.2, R156.1
unnamed: CP101.1, R126.2, R127.1
unnamed: CP102.1, R140.2, R141.1
unnamed: CP103.1, R154.2, R155.1
unnamed: D112.2 (A), J116.2
unnamed: D113.2 (A), R164.2
unnamed: J109.1, R122.2
unnamed: J109.2, R130.2
unnamed: J109.3, R136.2
unnamed: J110.1, Q108.1 (E), R133.2, R135.1
unnamed: J111.2, R144.2
unnamed: J112.1, Q109.1 (E), R147.2, R149.1
unnamed: J113.2, R150.2
unnamed: J114.2, R157.2
unnamed: J115.1, Q110.1 (E), R161.2, R163.1
unnamed: Q108.2 (B), R129.2
unnamed: Q109.2 (B), R143.2
unnamed: Q110.2 (B), R159.2
unnamed: R124.2, R128.2, U104.3 (+)
unnamed: R129.1, U104.6
unnamed: R133.1, R134.1, U104.2 (-)
unnamed: R139.2, R142.2, U105.3 (+)
unnamed: R143.1, U105.6
unnamed: R147.1, R148.1, U105.2 (-)
unnamed: R153.2, R156.2, U106.3 (+)
unnamed: R159.1, U106.6
unnamed: R161.1, R162.1, U106.2 (-)

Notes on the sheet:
Fuente de alimentación de 12V, 5V y 3,3V
Entradas para los sensores de corriente
Entradas para las tensiones provenientes de la batería.
Salidas de las tensiones de control de las fuentes de carga
Batería (+)
Cargador(+)
Batería (-)
+12,8V
GND
Al control de tensión de la fuente 2
Al control de tensión de la fuente 3
Sensor 1
Sensor 2
Sensor 3
Cargador(-)
Al control de tensión de la fuente 1

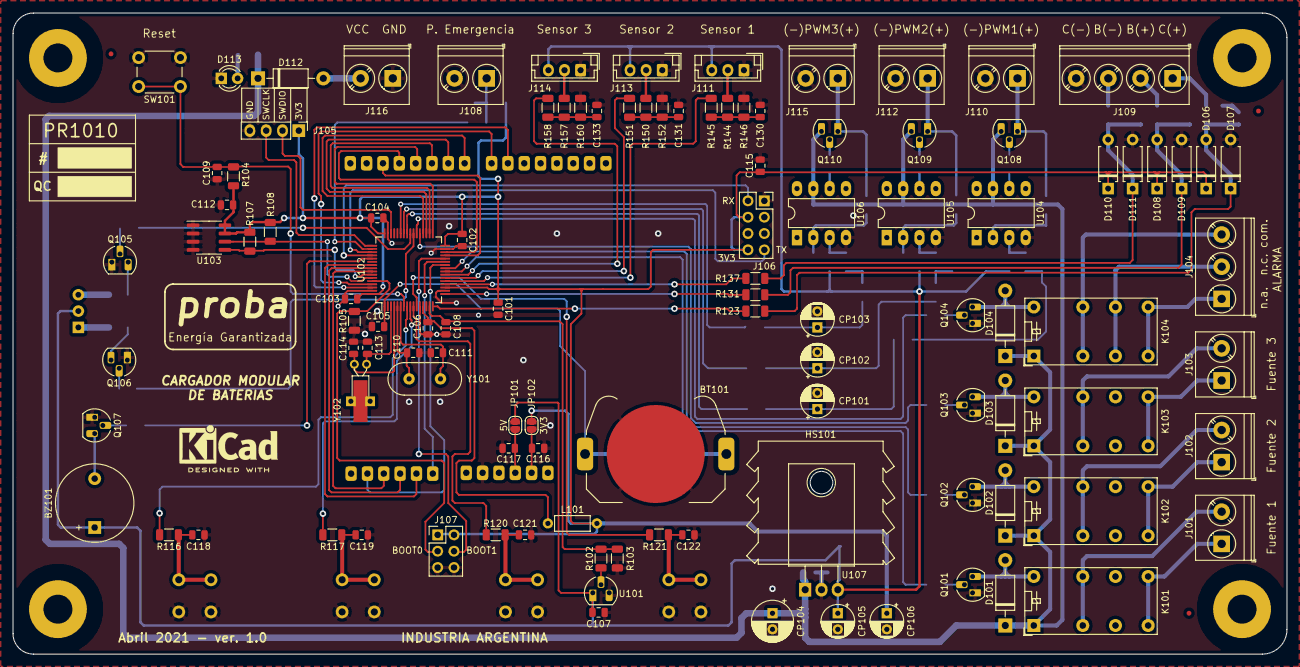
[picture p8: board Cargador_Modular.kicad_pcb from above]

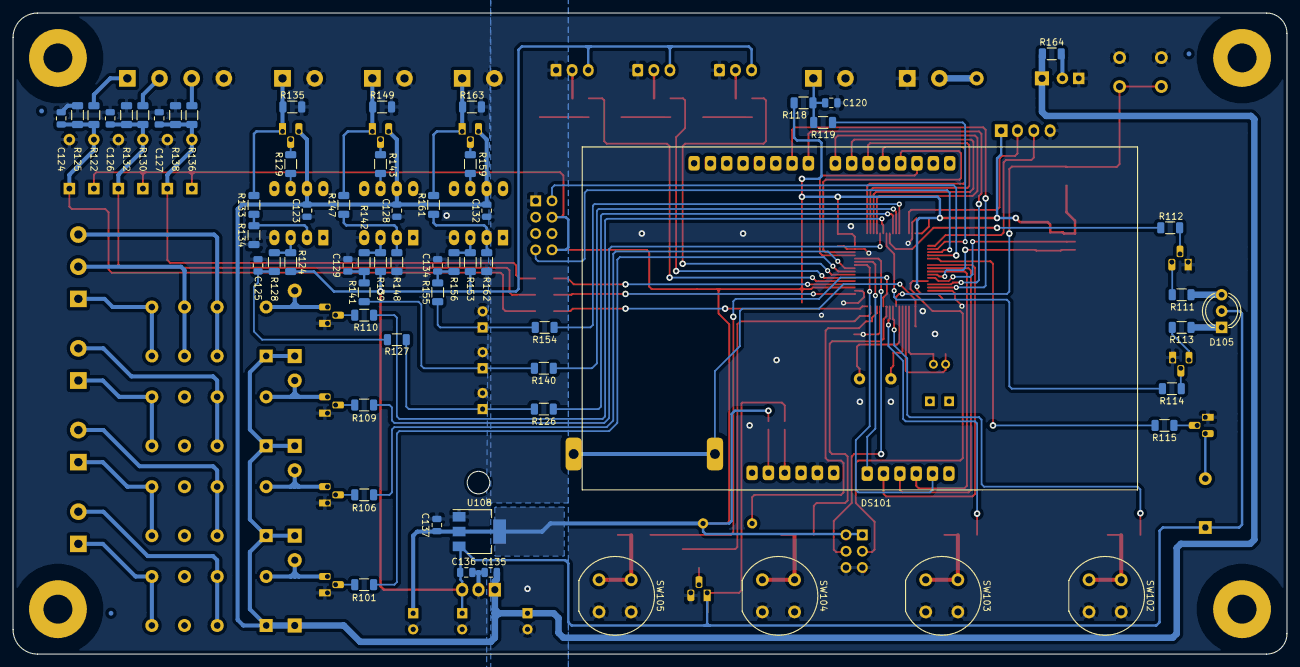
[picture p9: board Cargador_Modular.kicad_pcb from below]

Board: 2 copper layers, 198.1 x 99.7 mm, 182 parts (65 on the bottom side), 122 nets.

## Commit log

2021-03-21 confeccion esquematico
    [Cargador_Modular.kicad_pcb, Cargador_Modular.sch, Control.sch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]
2021-03-26 Se completa rotulo
    [Cargador_Modular.sch, Control.sch, Entradas_Salidas.sch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]
2021-03-26 Revisión y agregado de datasheet
    [Cargador_Modular.sch, Control.sch, Interface_Usuario.sch]
2021-03-28 se agregan descripciones a componentes del esquemático
    [Control.sch, Entradas_Salidas.sch, Interface_Usuario.sch]
2021-04-02 Se avanza con el ruteo del PCB
    [Cargador_Modular.kicad_pcb, Control.sch, Entradas_Salidas.sch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]
2021-04-10 Agrego agujeros de montaje y fiduciales al esquematico
    [Cargador_Modular.sch, Control.sch, Entradas_Salidas.sch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]
2021-04-10 se corrigen errores detectados con DRC
    [Cargador_Modular.kicad_pcb]
2021-04-15 Se cambio huella del portapilas y se completo el relleno de cobre
    [Cargador_Modular.kicad_pcb, Control.sch]
2021-04-15 se completa el relleno de cobre
    [Cargador_Modular.kicad_pcb]
2021-04-15 Update consideraciones de diseño
2021-04-17 Se finaliza el diseño del PCB
    [Cargador_Modular.kicad_pcb, Cargador_Modular.sch, Interface_Usuario.sch]
2021-04-17 Se agrga el modelo 3D
2021-04-21 Correccion power flag y digikey part
    [Control.sch, Entradas_Salidas.sch]
2021-04-21 Correccion bordes, fabricante y licencia
    [Cargador_Modular.kicad_pcb]
